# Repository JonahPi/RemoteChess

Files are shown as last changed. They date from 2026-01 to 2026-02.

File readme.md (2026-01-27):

## Summary

Remote Chess allows two board players or a board player and a App-user to compete online via a MQTT Broker. Lifting and placing of figures is detected by hall-sensors underneath the squares. The moves are published in an MQTT-topic called /remotechess. Boards subscribed to the topic get the moves from the topic and indicate them with NeoPixel LEDs which are integrated in the squares. Lifting a figure is indicated in red, placing a figure is indicated in green.

## Directory Structure

| Files / Directory | Description |
| --- | --- |
| [FSD Remote Chess.md](https://github.com/JonahPi/RemoteChess/blob/main/FSD%20Remote%20Chess.md) | Function Specification Document |
| CAD | CAD STEP File for Chess Board with electronic and cover |
| docs | Files used for Progressive Web App (PWA) published with Github Pages |
| Electronics | PCB schematic and Fritzing Files, Gerber Files |
| Micropython | ESP32 Micropython Program, Secrets File sample, Board-test-script, State-Diagram |
| pics | Project pictures |

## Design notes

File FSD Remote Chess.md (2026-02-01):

# FSD Remote Chess

## Summary

Remote Chess allows two board players to compete online via a MQTT Broker. Lifting and placing of figures is detected by hall-sensors underneath the squares. The moves are published in an MQTT-topic called /remotechess. Boards subscribed to the topic get the moves from the topic and indicate them with NeoPixel LEDs which are integrated in the squares. Lifting a figure is indicated in red, placing a figure is indicated in green.

## Board

The board has 8 times 8 fields setup in columns A to H and rows 1 to 8. Each field has a hall-sensor and a neopixel RGB LED.

The 64 Neopixel are organized in 8 rows so Fields A1 to H1 have the Neopixel numbers 1 to 8, the fields A2 to H2 have the Neopixel numbers 9 to 18 and so on till the fields A8 to H8 with Neopixel numbers 56 to 64.

The status of 64 hall sensors is detected by 8 PCBs, each of which has a MCP23017 GPIO Board Expander and 8 hall sensors to cover 1 row on the board. The 8 boards are all connected to an I2C bus. The board for the first row has the I2C address 0x27, the board for the second row has the address 0x26 and so on till the last row with board-address 0x20. The hall - sensors are connected to the  Inputs GPA0 to GPA7 of the Board expander, GPA0 corresponds to column A, GPA7 corresponds to column 7. 

##### Note: 

The ESP32 is located near the last row and the Neopixels are counted from there, this means that Fiel A8 (I2C address 0x20, GPA0) corresponds to the first Neopixel. Field H8 (I2C 0x27, GPA7) corresponds to the last Neopixel.

##### Concept

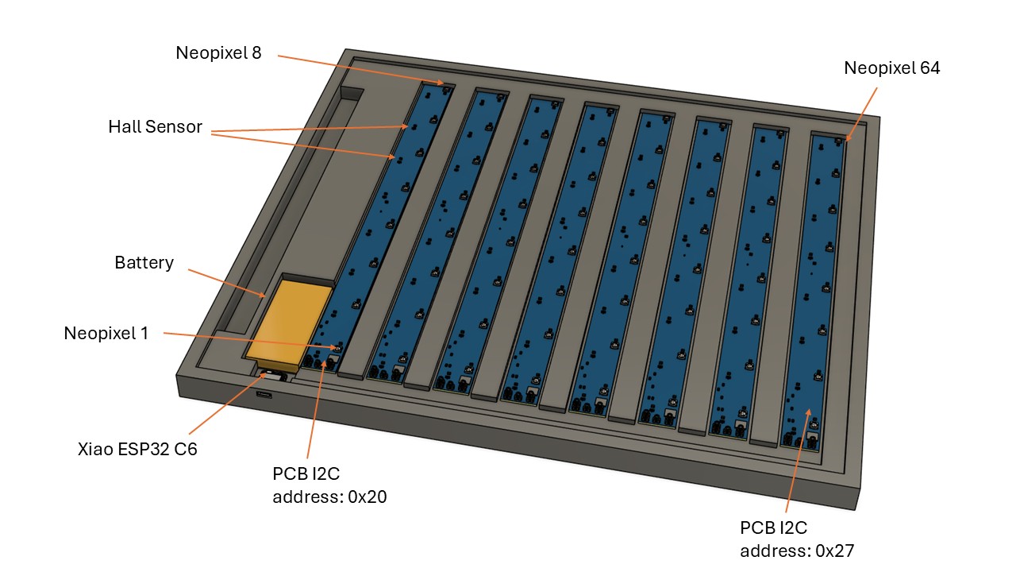
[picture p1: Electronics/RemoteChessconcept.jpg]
Remote Chess Concept


##### PCB Schematic (1x8 Row)

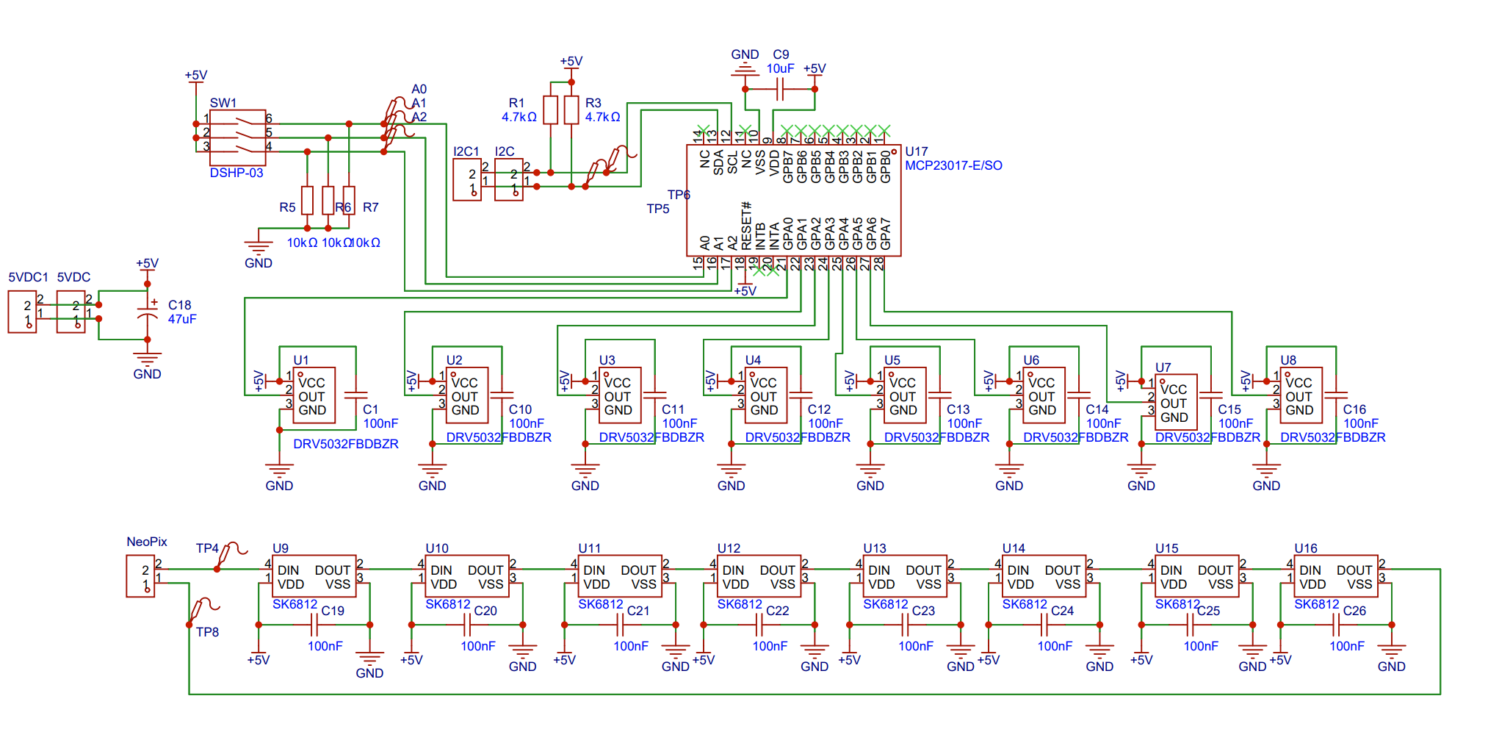
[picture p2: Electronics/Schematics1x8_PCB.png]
PCB Schematic for one row


| Quantity | Component | Comment |
| --- | --- | --- |
| 16 | 100nF | |
| 1 | 10uF | |
| 1 | 47uF | Stabilize Supply |
| 3 | 10kΩ | Pull up I2C address |
| 2 | 12kΩ | Pull up SDA, SCL |
| 1 | DSHP-03 | DIP-Switch for Address |
| 8 | DRV5032FBDBZR | Hall Sensor |
| 8 | SK6812 | Neopixel |
| 1 | MCP23017-E/SO | GPIO Port Expander |

#### Module test

The 8 PCBs shall be tested separately before the complete board assembly. To do this the I2C connections (SDA & SCL), the Neopixel data input (DIN) and the 5V input is directly connected to the XIAO ESP32-C6 (s.a. PIN assignement further below).

The test program has 3 steps:

1. Check if one of the permissible I2C addresses from 0x21 to 0x27 is set and print the address found in the serial terminal. 
2. Switch every single of the 8 Neopixel on and off in the 3 RGB colors, only one Neopixel at at a time shall be switched on. The frequency should be 500ms but configurable in a constant called frequency. So the test sequence looks like (Led 1 -> red -> green -> blue -> off, Led 2 -> red -> green -> blue -> off, ...and so on)
3. Switch in a loop which continuously detects the state of the hall-sensors, if a magnet is detected it should show the corresponding LED in green, if no magnet is detected the corresponding LED should be off. The brightness of the LEDs shall be reduced to 40%. Print the number of the hallsensors which detected a magnet in the serial window.

## ESP-Programming

### Program startup

During program startup, after initializing the hardware and before entering the main loop, the board shall perform a visual self-test by displaying the hall sensor status row by row:

1. For each row (1 to 8), read the hall sensor states and light up the corresponding LEDs for 1 second:
   - Fields with a magnet detected (figure present): RED
   - Fields without a magnet (no figure): GREEN
2. LED brightness during this startup routine shall be limited to 40%
3. After displaying a row for 1 second, turn off all LEDs before proceeding to the next row
4. After all 8 rows have been displayed, turn off all LEDs and proceed to the main loop

This startup sequence serves as a visual confirmation that all hall sensors and LEDs are functioning correctly. 

The startup sequence shall also be called when a re-start is triggered.

### Connection indication

After successfully connecting to the MQTT broker and subscribing to the topic, display a brief visual indication that the game is ready to start:

1. Light up D4 and E4 in green (place color)
2. Light up D5 and E5 in red (lift color)
3. Keep LEDs on for 1 second, then turn them off

This pattern indicates the center of the board and confirms the connection is established.

### Detecting and publishing movement

Figure movements is detected by a change in the hall-sensor state and indicated with LEDs, the actions cause MQTT messages to be send. The logic is defined in the state-diagram below.

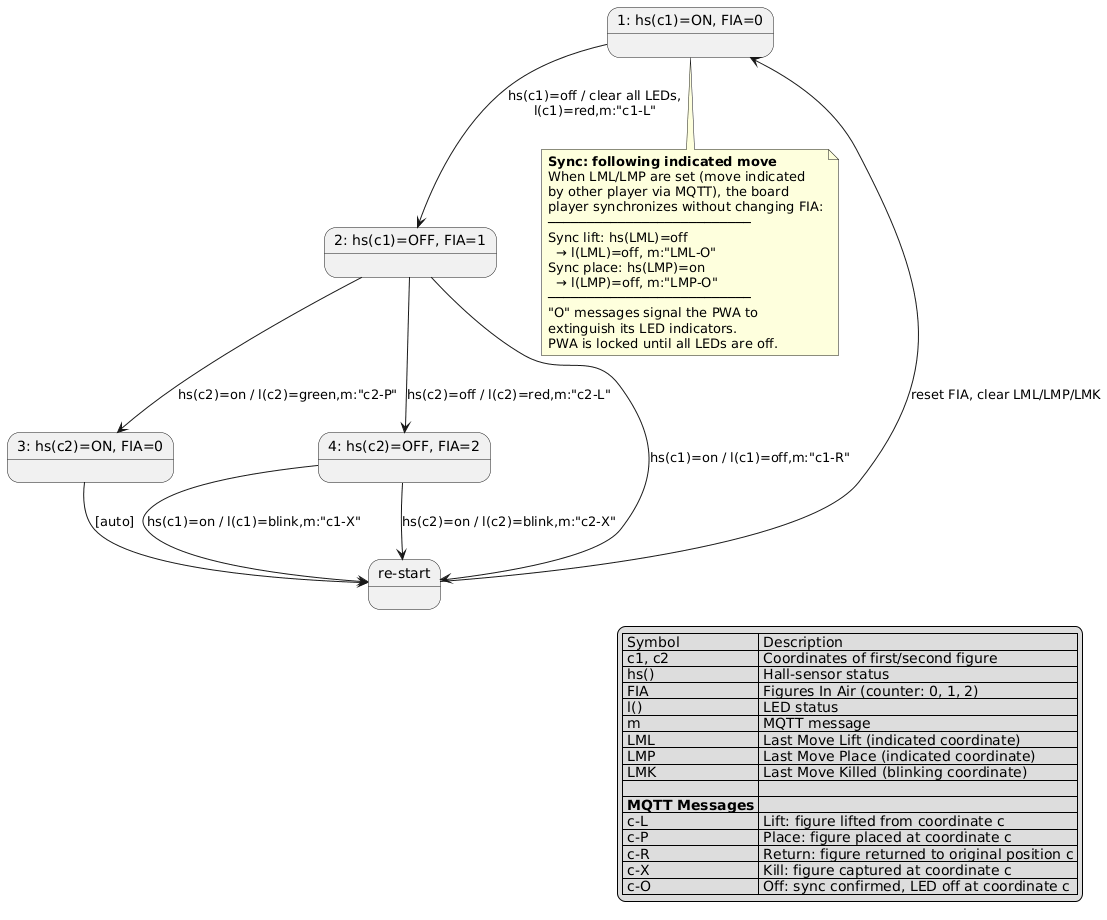
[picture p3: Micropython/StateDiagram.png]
StateDiagram


**Important:** The state variables LML, LMP and LMK shall only be updated by the MQTT callback when receiving messages, not by the hall sensor scanning function. This ensures that when the board receives its own published message, the LED control works correctly (the callback clears the OLD coordinates before setting the new ones). The hall sensor scanning function shall only update FiguresInAir and publish MQTT messages.

### Receiving and Indicating movement

New messages on topic /remotechess shall trigger the following actions:

| Message format | Action |
| --- | --- |
| *coordinate*-L | 1. switch the Neopixel corresponding to *coordinate* to red<br />2. set neopixels corresponding to coordinates stored in LML, LMP and LMK to *off* (skip if the variable is empty)<br />3. set values of LMP and LMK to ""<br />4. set value of LML to *coordinate*<br />5. stop the timer "fading" |
| *coordinate*-P | 1. switch the neopixel corresponding to *coordinate* to green<br />2. reset/start the timer "fading" and set it to 20s<br />3. set value of LMP to *coordinate*<br />4. if LMK is not empty, set it to "" and stop the blinking |
| *coordinate*-R | 1. switch the neopixel corresponding to *coordinate* to *off*<br />2. set value of LML to "" |
| *coordinate*-X | 1. switch the neopixel corresponding to *coordinate* to red blinking (200ms frequency)<br />2. set value of LMK to *coordinate*<br />3. reset/start the timer "fading" and set it to 20s |

When the timer fading expires, the Neopixels corresponding to the coordinates stored in LML, LMP and LMK shall be switched to *off* and all LEDs shall be switched to off.

### Moving figures to follow indicated movement

When the player receives a move which is indicated by the red and green LEDs, he is supposed to synchronize the figures on the chess field with the indicated move. This synchronization shall not trigger a MQTT message. As soon as he lifts the figure to be synchronized from the correct position, the red led shall be switched off, when he places the figure on the correct field the green LED shall be switched off. It is important that the "on"->"off" sequence (figure is lifted) and the "off"->"on" sequence (figure is placed) are correctly detected. In case a figure is killed in that move, the destination hall-sensor is "on" in the beginning. The figure to be killed is then lifted (on->off: which should not cause any action) and the new figure is placed (off->on: switching off green destination LED).

Till the move has been synchronized on the board, it shall not be possible to make a new move in the PWA. That the move has been synchronized on the board shall be indicated in the PWA by extinguishing the LEDs which indicated the movement in the app.

### Pin-assignment

The program shall be written in Micropython and suitable for the development board Xiao ESP32-C6. Use the following pins:

| Function | Pin Number |
| --- | --- |
| SCL | D5 |
| SDA | D4 |
| Neopixel | D7 |

### Secrets file

The access data (passwords, usernames, keys and IP-addresses) for the the Wifi and to the MQTT broker shall be stored in a dedicated secrets - file.

Time values, Blink-frequency and LED-colors shall be settable at the top of the pro

### MQTT Broker

Use the following MQTT Broker Configuration

```
MQTT_BROKER = "io.adafruit.com"  
MQTT_PORT = 1883                         # Default MQTT port
MQTT_USER = "your_adafruit_username"
MQTT_PASSWORD = "your_adafruit_key"      # Look for key-symbol in your adafruit account
MQTT_CLIENT_ID = "remote_chess_board_1"  # Unique ID for this board
MQTT_TOPIC = "YourUserName/feeds/chess"  # MQTT topic for chess moves, adapt your username
```

### Demo mode

Add a flag DemoMode which can be set at the beginning of the program. In demo-mode the hall-sensors are not connected and no expander boards. In this mode the program shall just check for the updates on the MQTT topic and control the neopixel stripe with 64 LEDs. The received updates and the color and number of the activated neopixel shall be shown in the serial monitor.

## **Progressive Web App (PWA**)

### Summary

The Web App allows the simulation of the real chess board. So one player can use the app and the other player uses the real board. Alternatively both players can use the app or both players can use a real board

### Architecture

The Web App shall be hosted as page in the Git-repository for this project ([Remote Chess](https://jonahpi.github.io/RemoteChess/)). The Web App shall simulate the Chess-board and shall be optimized for an iPhone 16 from the layout. By touching a figure ones it is activated for moving. Touching a field afterwards will place the figure there. In case the destination field was not empty, the destination figure is replaced with the figure which has been selected. When moving the figures no chess rules need to be considered. Touching the figure shall have the same effect as lifting a figure on the real chess box including the MQTT message. The LEDs shall be simulated by small dots on the simulated chess field. 

When starting the program it shall automatically try to connect, when it gets disconnected it shall try to reconnect.

A button called "Zurück" allows to undo the latest action on App. It will move the figures which has been moved by the user back to the last position, the LEDs are switched off and in case another figure has been killed, the figure should be replaced to its original position. "Zurück" only needs to work for one move. the button shall be greyed out when it has been used and re-activated after the next move. When "Zurück" has been clicked, send the message "undo" to the MQTT topic. When receiving the MQTT message "undo", undo the last figure placement.

A button called "Neu starten" will reset the board to the start position. White is on the bottom, black on the top. This will also trigger the startup-sequence and a MQTT message "restart". The MQTT message indicates the other player that the game has restarted. When the ESP32 receives the "restart" message, the startup-sequence shall be triggered.

A button called "Wechsel" shall flip the entire board updside down, so that the player sees the black figures on the bottom and the white figures on the top. Pressing the button again, switches back to the original setup with white figures on the bottom and black on the top.

When the App receives a MQTT message of type *coordinate*-L which has not been triggered by touching a figure in the app itself, this means that the other player has lifted a figure. The App shall then wait for the message that a figure has been placed (*coordinate*-P) and move the corresponding icon from the lift-coordinates to the place-coordinates.

When the lift location and the place location of a pawn is the same and the pawn is in row 1 or in row 8, change the pawn to a Queen, if it is lifted and placed again to the same location, change it back to a pawn. All other figures and pawns in all other rows, shall remain the same when they are lifted and placed on the same location.

### Icon Design

 All chess figures are depicted by simple icons. the Icons for one player shall be black, the ones for the other player white

1. **Black pieces** - Displayed in pure black color (#000)
2. **White pieces** - Displayed in white with a black outline/shadow so they're visible on light squares
3. **Consistent rendering** - All pieces now use the same Unicode symbols but with CSS styling to ensure they look uniform
4. **Black party**: Black icons (♚ ♛ ♜ ♝ ♞ ♟)
5. **White party**: White icons with black outline (♔ ♕ ♖ ♗ ♘ ♙)
6. Enforce the usage of the fonts `Noto Sans Symbols` or `Chess Merida`for rendering the symbols.

### Screen Layout

The chess board shall be square an take the full width of the screen. On the top shall be a status indication which states if the program is still connected to the MQTT Broker. 

Below the chess board, the 3 buttons are placed in the order: Wechsel, Zurück, Neu starten

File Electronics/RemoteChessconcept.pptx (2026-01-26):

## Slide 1

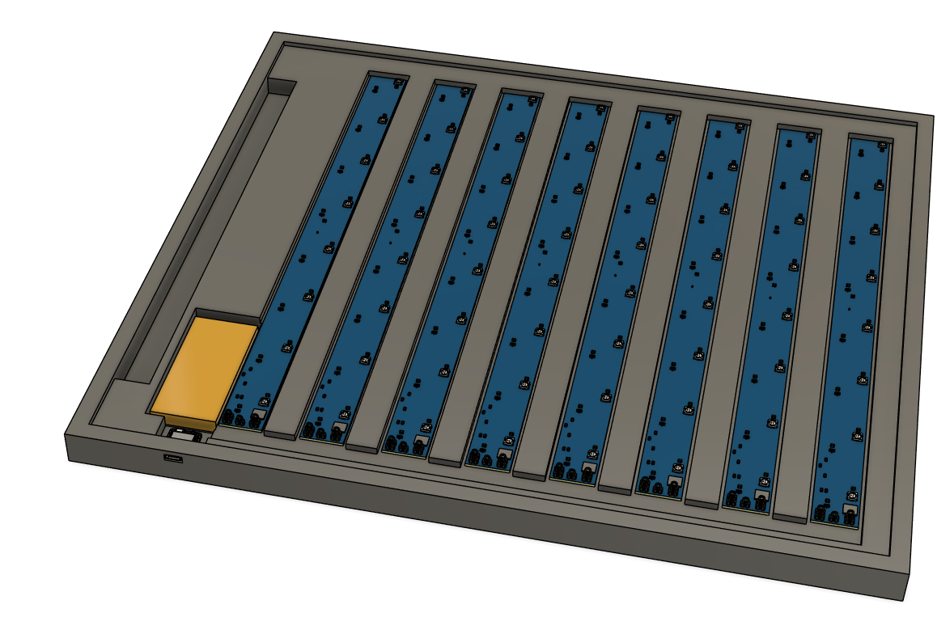
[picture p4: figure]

Neopixel 8

Neopixel 64

Hall Sensor

Battery

Neopixel 1

Xiao ESP32 C6

PCB I2C
address: 0x20

PCB I2C
address: 0x27

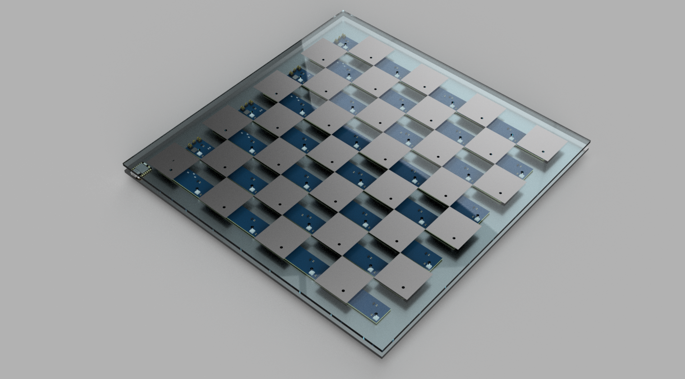
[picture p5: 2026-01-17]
pics/RemoteChess v5.png

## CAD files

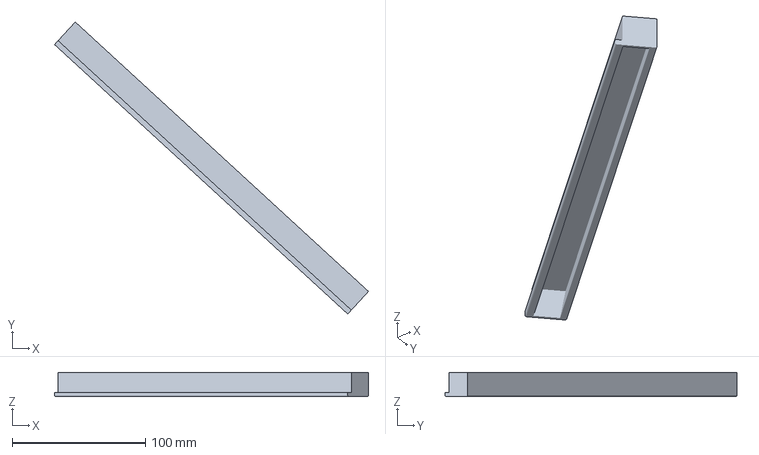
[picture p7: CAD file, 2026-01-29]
CAD/ipadInlay.3mf
235.3 x 218.8 x 18.0 mm

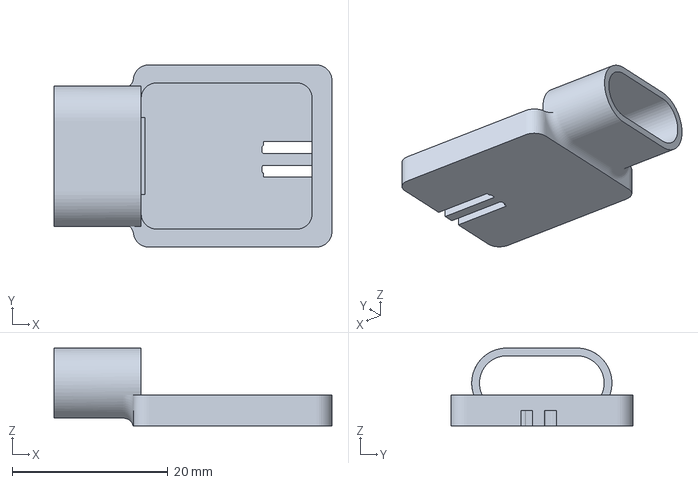
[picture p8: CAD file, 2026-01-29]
CAD/ESP32_Inlay.3mf
35.7 x 23.4 x 10.0 mm

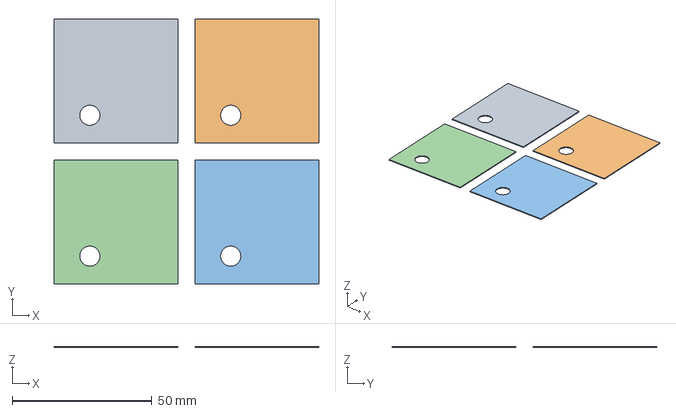
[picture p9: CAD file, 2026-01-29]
CAD/4xChessFields.3mf
94.8 x 94.8 x 0.4 mm

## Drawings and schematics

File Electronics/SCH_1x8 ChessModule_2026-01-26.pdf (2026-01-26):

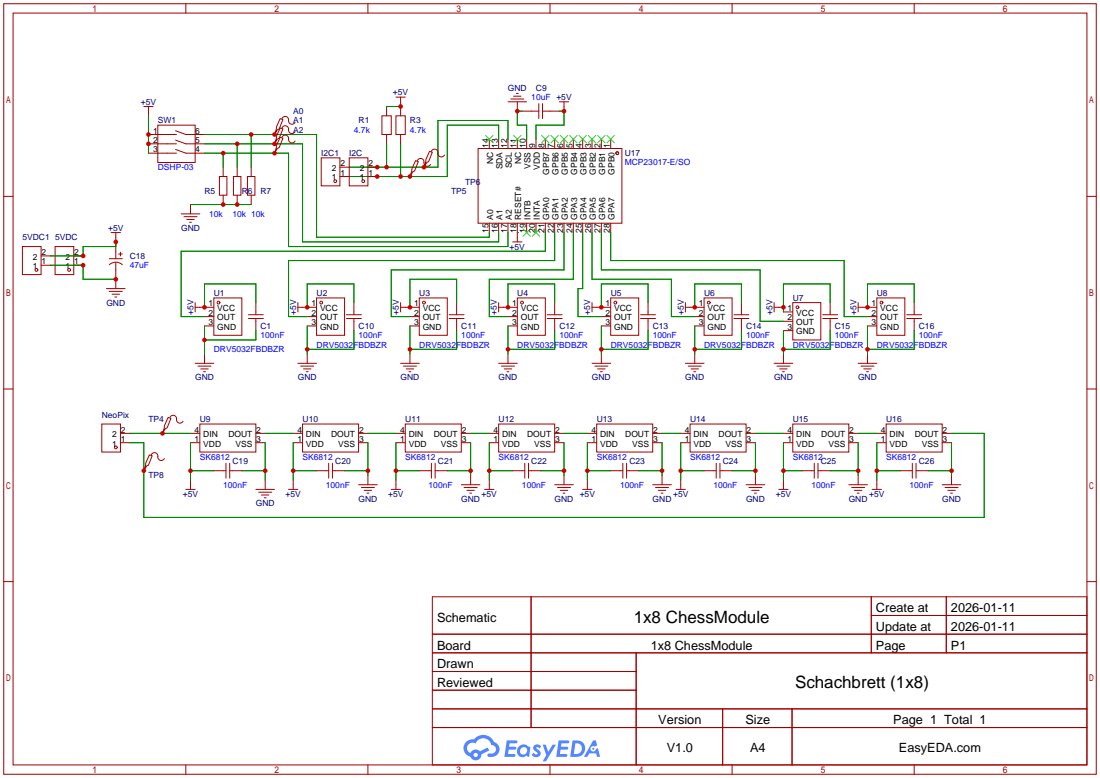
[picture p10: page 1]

9 VSS 10 NC 11 SCL 12 SDA 13 NC 14 A0 15 A1 16 A2 17 RESET# 18 INTB 19 INTA 20

Schematic | 1x8 ChessModule | Create at | 2026-01-11

Update at | 2026-01-11

Board | 1x8 ChessModule | Page | P1
Drawn | | Schachbrett (1x8)
Reviewed

Version | Size | Page 1 Total 1
V1.0 | A4 | EasyEDA.com

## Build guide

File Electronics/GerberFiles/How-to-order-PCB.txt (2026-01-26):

How to Order PCB

Please refer to:
https://prodocs.easyeda.com/en/pcb/order-order-pcb/index.html

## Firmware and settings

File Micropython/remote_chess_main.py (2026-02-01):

"""
FSD Remote Chess - Main Program
For Xiao ESP32-C6 with MicroPython
"""

import network
import time
import json
import socket
from machine import Pin, I2C, Timer
from neopixel import NeoPixel
from umqtt.simple import MQTTClient
from secrets import *

# ============= CONFIGURATION =============
# Demo Mode - Set to True to run without hall sensors
DEMO_MODE = False  # Set to True for testing without hardware

# LED Colors (R, G, B)
COLOR_LIFT = (100, 0, 0)      # Red for lifted pieces
COLOR_PLACE = (0, 100, 0)     # Green for placed pieces
COLOR_KILLED = (100, 0, 0)    # Red for killed pieces
COLOR_OFF = (0, 0, 0)         # Off

# Timing
FADING_TIMEOUT_MS = 15000     # 20 seconds
BLINK_FREQUENCY_MS = 400      # 200ms for blinking
STARTUP_ROW_DURATION_MS = 800  # 800ms per row during startup

# Startup brightness (40% = 0.4)
STARTUP_BRIGHTNESS = 0.4

# Pin Configuration (Xiao ESP32-C6)
PIN_SDA = 22  # D4 = GPIO22
PIN_SCL = 23  # D5 = GPIO23
PIN_NEOPIXEL = 18  # D10 = GPIO18

# Board Configuration
NUM_NEOPIXELS = 64
MCP23017_ADDRESSES = [0x20, 0x21, 0x22, 0x23, 0x24, 0x25, 0x26, 0x27]

# ============= GLOBAL VARIABLES =============
LML = ""  # Last Move Lift
LMP = ""  # Last Move Place
LMK = ""  # Last Move Killed (coordinate with blinking LED)

# State machine variables per FSD
FiguresInAir = 0  # Counter: 0, 1, or 2
first_lift_coord = ""  # Coordinate of first lifted piece (c1)
second_lift_coord = ""  # Coordinate of second lifted piece (c2)

# Hardware objects
i2c = None
np = None
mqtt_client = None
fading_timer = None
blink_timer = None
blink_state = False

# Track previous hall sensor states (only used in non-demo mode)
previous_hall_states = [[False] * 8 for _ in range(8)]

# MQTT keep-alive tracking
last_mqtt_activity = 0  # Reset on any MQTT publish

# ============= MCP23017 Functions =============
def mcp23017_init(i2c, address):
    """Initialize MCP23017 - set all pins as inputs with pull-ups"""
    # IODIRA register (0x00) - set all as inputs (0xFF)
    i2c.writeto_mem(address, 0x00, b'\xFF')
    # GPPUA register (0x0C) - enable pull-ups
    i2c.writeto_mem(address, 0x0C, b'\xFF')

def mcp23017_read_gpio(i2c, address):
    """Read GPIOA register (0x12) from MCP23017"""
    data = i2c.readfrom_mem(address, 0x12, 1)
    return data[0]

# ============= Coordinate Conversion =============
def sensor_to_coordinate(row_idx, col):
    """Convert row_idx (0-7) and column (0-7) to chess coordinate.

    Note: I2C addresses are mapped as follows:
    - row_idx 0 (I2C 0x20) = Chess Row 8
    - row_idx 7 (I2C 0x27) = Chess Row 1
    """
    column_letter = chr(ord('A') + col)
    row_number = 8 - row_idx  # row_idx 0 -> row 8, row_idx 7 -> row 1
    return f"{column_letter}{row_number}"

def coordinate_to_neopixel(coord):
    """Convert chess coordinate (e.g., 'A1') to neopixel index (0-63).

    Note: Neopixels are counted from A8 (index 0) to H1 (index 63).
    - A8 = 0, H8 = 7
    - A1 = 56, H1 = 63
    """
    col = ord(coord[0]) - ord('A')
    chess_row = int(coord[1])
    row_idx = 8 - chess_row  # row 8 -> idx 0, row 1 -> idx 7
    return row_idx * 8 + col

# ============= NeoPixel Functions =============
def set_neopixel(coord, color):
    """Set neopixel at coordinate to specified color"""
    if coord:
        idx = coordinate_to_neopixel(coord)
        np[idx] = color
        np.write()
        if DEMO_MODE:
            print(f"[DEMO] NeoPixel #{idx} ({coord}) -> RGB{color}")

def clear_neopixels(coords):
    """Clear neopixels at given coordinates"""
    for coord in coords:
        if coord:
            set_neopixel(coord, COLOR_OFF)

def blink_callback(timer):
    """Timer callback for blinking effect"""
    global blink_state, LMK
    if LMK:
        blink_state = not blink_state
        color = COLOR_KILLED if blink_state else COLOR_OFF
        set_neopixel(LMK, color)

def fading_callback(timer):
    """Timer callback for fading timeout"""
    global LML, LMP, LMK
    if DEMO_MODE:
        print(f"[DEMO] Fading timeout - clearing all LEDs")
    # Clear specific coordinates
    clear_neopixels([LML, LMP, LMK])
    # Clear all LEDs
    for i in range(NUM_NEOPIXELS):
        np[i] = COLOR_OFF
    np.write()
    # Reset state variables
    LML = ""
    LMP = ""
    LMK = ""
    if blink_timer:
        blink_timer.deinit()

# ============= MQTT Functions =============
def mqtt_callback(topic, msg):
    """Handle incoming MQTT messages"""
    global LML, LMP, LMK, fading_timer, blink_timer, previous_hall_states

    message = msg.decode('utf-8')
    print(f"Received: {message}")

    # Handle restart message
    if message == "restart":
        global FiguresInAir, first_lift_coord, second_lift_coord
        print("Restart triggered - running startup sequence")
        # Clear all state
        LML = ""
        LMP = ""
        LMK = ""
        FiguresInAir = 0
        first_lift_coord = ""
        second_lift_coord = ""
        if fading_timer:
            fading_timer.deinit()
        if blink_timer:
            blink_timer.deinit()
        # Clear all LEDs
        for i in range(NUM_NEOPIXELS):
            np[i] = COLOR_OFF
        np.write()
        # Run startup sequence and re-read hall sensor states
        if not DEMO_MODE:
            startup_led_test()
            # Re-initialize hall sensor states after restart
            for row_idx, address in enumerate(MCP23017_ADDRESSES):
                try:
                    gpio_state = mcp23017_read_gpio(i2c, address)
                    for col_idx in range(8):
                        previous_hall_states[row_idx][col_idx] = (gpio_state & (1 << col_idx)) == 0
                except Exception as e:
                    print(f"Error reading state after restart: {e}")
        return

    if len(message) < 4:
        return

    coord = message[:-2]  # Extract coordinate (e.g., 'A4' from 'A4-L')
    action = message[-1]  # Extract action ('L', 'P', 'R', or 'X')
    
    if action == 'L':
        # Lift action
        if DEMO_MODE:
            print(f"[DEMO] Lift detected at {coord}")
        set_neopixel(coord, COLOR_LIFT)
        clear_neopixels([LML, LMP, LMK])
        LMP = ""
        LMK = ""
        LML = coord
        if fading_timer:
            fading_timer.deinit()
    
    elif action == 'P':
        # Place action
        if DEMO_MODE:
            print(f"[DEMO] Place detected at {coord}")
        set_neopixel(coord, COLOR_PLACE)
        LMP = coord
        # If LMK is not empty, clear it and stop blinking
        if LMK:
            if DEMO_MODE:
                print(f"[DEMO] Clearing killed piece at {LMK} and stopping blink")
            LMK = ""
            if blink_timer:
                blink_timer.deinit()
        if fading_timer:
            fading_timer.deinit()
        fading_timer = Timer(0)
        fading_timer.init(mode=Timer.ONE_SHOT, period=FADING_TIMEOUT_MS, callback=fading_callback)

    elif action == 'R':
        # Return action - figure returned to original position
        if DEMO_MODE:
            print(f"[DEMO] Figure returned to {coord}")
        set_neopixel(coord, COLOR_OFF)
        LML = ""

    elif action == 'X':
        # Killed action
        if DEMO_MODE:
            print(f"[DEMO] Piece killed at {coord}")
        LMK = coord
        if blink_timer:
            blink_timer.deinit()
        blink_timer = Timer(1)
        blink_timer.init(mode=Timer.PERIODIC, period=BLINK_FREQUENCY_MS, callback=blink_callback)
        # Start fading timer so blinking LED turns off after timeout
        if fading_timer:
            fading_timer.deinit()
        fading_timer = Timer(0)
        fading_timer.init(mode=Timer.ONE_SHOT, period=FADING_TIMEOUT_MS, callback=fading_callback)

    elif action == 'O':
        # Sync indication echo from board - ignore on receive
        pass

def publish_move(message):
    """Publish move to MQTT topic"""
    global last_mqtt_activity
    try:
        mqtt_client.publish(MQTT_TOPIC, message)
        last_mqtt_activity = time.time()  # Reset ping timer
        print(f"Published: {message}")
    except Exception as e:
        print(f"MQTT publish error: {e}")

# ============= Hall Sensor Scanning =============
def scan_hall_sensors():
    """Scan all hall sensors and detect changes.

    State machine per FSD:
    - State 1: FIA=0, waiting for first lift
    - State 2: FIA=1, one piece lifted (c1)
    - State 3: FIA=0, piece placed (move complete)
    - State 4: FIA=2, two pieces lifted (capture scenario)

    Transitions:
    - State 1 → 2: lift → FIA=1, send "c1-L"
    - State 2 → 3: place at new coord → FIA=0, send "c2-P"
    - State 2 → 4: lift second piece → FIA=2, send "c2-L"
    - State 4 → restart: place → FIA=0, send "cX-X" (capture)
    - State 2 → restart: place back at c1 → FIA=0, send "c1-P"

    When LEDs indicate a move from the other player (LML/LMP set),
    synchronizing figures to follow that move does NOT trigger MQTT messages.
    """
    global FiguresInAir, first_lift_coord, second_lift_coord, previous_hall_states, LML, LMP, LMK, fading_timer, blink_timer

    for row_idx, address in enumerate(MCP23017_ADDRESSES):
        try:
            gpio_state = mcp23017_read_gpio(i2c, address)

            for col_idx in range(8):
                # Check if bit is LOW (0 = magnet detected = figure present, with pull-ups)
                current_state = (gpio_state & (1 << col_idx)) == 0
                previous_state = previous_hall_states[row_idx][col_idx]

                # Detect state change
                if current_state != previous_state:
                    coord = sensor_to_coordinate(row_idx, col_idx)

                    # Figure removed (was present, now absent)
                    if previous_state and not current_state:
                        # Check if this is synchronizing to an indicated move (lift from LML)
                        if coord == LML:
                            # Player is following indicated move - indicate sync to PWA
                            print(f"Sync lift at {coord} (following indicated move)")
                            set_neopixel(coord, COLOR_OFF)
                            LML = ""
                            publish_move(f"{coord}-O")
                        elif FiguresInAir == 0:
                            # State 1 → State 2: First lift
                            # FSD: restart → State 1 clears all LEDs
                            clear_neopixels([LML, LMP, LMK])
                            LML = ""
                            LMP = ""
                            LMK = ""
                            if fading_timer:
                                fading_timer.deinit()
                            if blink_timer:
                                blink_timer.deinit()
                            FiguresInAir = 1
                            first_lift_coord = coord
                            publish_move(f"{coord}-L")
                        elif coord == LMP:
                            # Player is removing killed piece from destination - no action
                            # Green LED stays on until new piece is placed
                            print(f"Sync kill removal at {coord} (removing captured piece)")
                        elif FiguresInAir == 1:
                            # State 2 → State 4: Second lift (capture scenario)
                            FiguresInAir = 2
                            second_lift_coord = coord
                            publish_move(f"{coord}-L")  # FSD: send L, not X

                    # Figure placed (was absent, now present)
                    elif not previous_state and current_state:
                        # Check if this is synchronizing to an indicated move (place at LMP)
                        if coord == LMP:
                            # Player is following indicated move - indicate sync to PWA
                            print(f"Sync place at {coord} (following indicated move)")
                            set_neopixel(coord, COLOR_OFF)
                            LMP = ""
                            publish_move(f"{coord}-O")
                        elif FiguresInAir == 1:
                            # State 2: One piece in air
                            if coord == first_lift_coord:
                                # State 2 → restart: Return to original position
                                FiguresInAir = 0
                                first_lift_coord = ""
                                publish_move(f"{coord}-R")  # FSD: send R for return
                            else:
                                # State 2 → State 3 → restart: Normal move
                                FiguresInAir = 0
                                first_lift_coord = ""
                                publish_move(f"{coord}-P")
                        elif FiguresInAir == 2:
                            # State 4 → restart: Capture placement
                            # When placing while 2 pieces are in air, this is a capture
                            FiguresInAir = 0
                            first_lift_coord = ""
                            second_lift_coord = ""
                            publish_move(f"{coord}-X")  # FSD: send X for capture

                    previous_hall_states[row_idx][col_idx] = current_state

        except Exception as e:
            print(f"Error reading MCP23017 at 0x{address:02X}: {e}")

# ============= Startup Routine =============
def startup_led_test():
    """Display hall sensor status row by row during startup"""
    print("Running startup LED test...")

    # Calculate dimmed colors (40% brightness)
    color_red = tuple(int(c * STARTUP_BRIGHTNESS) for c in COLOR_LIFT)
    color_green = tuple(int(c * STARTUP_BRIGHTNESS) for c in COLOR_PLACE)

    for row_idx, address in enumerate(MCP23017_ADDRESSES):
        try:
            # Read hall sensor state for this row
            gpio_state = mcp23017_read_gpio(i2c, address)

            # Light up LEDs for this row
            for col_idx in range(8):
                # Check if magnet detected (LOW = magnet present)
                magnet_present = (gpio_state & (1 << col_idx)) == 0
                led_idx = row_idx * 8 + col_idx

                if magnet_present:
                    np[led_idx] = color_red    # Red for magnet/figure present
                else:
                    np[led_idx] = color_green  # Green for no magnet/empty

            np.write()
            print(f"Row {row_idx + 1} (0x{address:02X}): displayed")

            # Wait 1 second
            time.sleep(STARTUP_ROW_DURATION_MS / 1000)

            # Turn off this row before next
            for col_idx in range(8):
                led_idx = row_idx * 8 + col_idx
                np[led_idx] = COLOR_OFF
            np.write()

        except Exception as e:
            print(f"Error in startup test row {row_idx + 1}: {e}")

    print("Startup LED test complete")

# ============= WiFi Manager =============
WIFI_CONFIG_FILE = "wifi_config.json"
AP_SSID = "RemoteChess-Setup"

def url_decode(s):
    """Simple URL decoder for form data"""
    s = s.replace('+', ' ')
    parts = s.split('%')
    result = parts[0]
    for part in parts[1:]:
        if len(part) >= 2:
            try:
                result += chr(int(part[:2], 16)) + part[2:]
            except ValueError:
                result += '%' + part
        else:
            result += '%' + part
    return result

def load_wifi_config():
    """Load WiFi credentials from permanent storage"""
    try:
        with open(WIFI_CONFIG_FILE, 'r') as f:
            config = json.load(f)
            return config.get('ssid', ''), config.get('password', '')
    except:
        return '', ''

def save_wifi_config(ssid, password):
    """Save WiFi credentials to permanent storage"""
    config = {'ssid': ssid, 'password': password}
    with open(WIFI_CONFIG_FILE, 'w') as f:
        json.dump(config, f)
    print(f"WiFi config saved for network: {ssid}")

def scan_wifi_networks():
    """Scan for available WiFi networks"""
    wlan = network.WLAN(network.STA_IF)
    wlan.active(True)
    networks = wlan.scan()
    wlan.active(False)
    seen = set()
    unique = []
    for net in networks:
        ssid = net[0].decode('utf-8') if isinstance(net[0], bytes) else net[0]
        if ssid and ssid not in seen:
            seen.add(ssid)
            unique.append((ssid, net[3]))
    unique.sort(key=lambda x: x[1], reverse=True)
    return unique

def generate_wifi_html(networks):
    """Generate HTML page for WiFi network selection"""
    options = ''
    for ssid, rssi in networks:
        options += '<option value="' + ssid + '">' + ssid + ' (' + str(rssi) + ' dBm)</option>'
    return ('<!DOCTYPE html><html><head>'
        '<meta name="viewport" content="width=device-width, initial-scale=1">'
        '<title>Remote Chess WiFi Setup</title>'
        '<style>'
        'body{font-family:Arial;margin:20px;background:#1a1a2e;color:#eee;}'
        'h1{color:#e94560;}h2{color:#aaa;}'
        'select,input,button{width:100%;padding:12px;margin:8px 0;'
        'box-sizing:border-box;font-size:16px;border-radius:4px;border:1px solid #555;}'
        'select,input{background:#16213e;color:#eee;}'
        'button{background:#e94560;color:white;border:none;cursor:pointer;}'
        '.c{max-width:400px;margin:0 auto;}'
        '</style></head><body><div class="c">'
        '<h1>Remote Chess</h1><h2>WiFi Setup</h2>'
        '<form action="/connect" method="POST">'
        '<label>Select Network:</label>'
        '<select name="ssid">' + options + '</select>'
        '<label>Password:</label>'
        '<input type="password" name="password" placeholder="Enter WiFi password">'
        '<button type="submit">Connect</button>'
        '</form></div></body></html>')

def start_wifi_manager():
    """Start WiFi Manager AP with web portal for network selection"""
    print("Scanning WiFi networks...")
    networks = scan_wifi_networks()
    print(f"Found {len(networks)} networks")

    ap = network.WLAN(network.AP_IF)
    ap.active(True)
    ap.config(essid=AP_SSID)

    print(f"WiFi Manager AP started: {AP_SSID}")
    print("Connect to this network and open http://192.168.4.1")

    addr = socket.getaddrinfo('0.0.0.0', 80)[0][-1]
    s = socket.socket()
    s.setsockopt(socket.SOL_SOCKET, socket.SO_REUSEADDR, 1)
    s.bind(addr)
    s.listen(1)

    html_page = generate_wifi_html(networks)

    try:
        while True:
            cl, cl_addr = s.accept()
            try:
                request = cl.recv(1024).decode('utf-8')

                if 'POST /connect' in request:
                    body = request.split('\r\n\r\n')[-1]
                    params = {}
                    for param in body.split('&'):
                        if '=' in param:
                            key, value = param.split('=', 1)
                            params[key] = url_decode(value)

                    ssid = params.get('ssid', '')
                    password = params.get('password', '')

                    if ssid:
                        response = ('<!DOCTYPE html><html><head>'
                            '<meta name="viewport" content="width=device-width, initial-scale=1">'
                            '<style>body{font-family:Arial;margin:20px;background:#1a1a2e;'
                            'color:#eee;text-align:center;}h1{color:#e94560;}</style>'
                            '</head><body>'
                            '<h1>Connecting to ' + ssid + '...</h1>'
                            '<p>The board will connect to the selected network.</p>'
                            '<p>You can close this page.</p>'
                            '</body></html>')
                        cl.send('HTTP/1.0 200 OK\r\nContent-Type: text/html\r\n\r\n')
                        cl.send(response)
                        cl.close()

                        save_wifi_config(ssid, password)
                        ap.active(False)
                        s.close()
                        return ssid, password
                else:
                    cl.send('HTTP/1.0 200 OK\r\nContent-Type: text/html\r\n\r\n')
                    cl.send(html_page)
            except Exception as e:
                print(f"WiFi Manager error: {e}")
            finally:
                try:
                    cl.close()
                except:
                    pass
    except Exception as e:
        print(f"WiFi Manager server error: {e}")
        s.close()
        ap.active(False)
        raise
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

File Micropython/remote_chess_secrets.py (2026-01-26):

"""
FSD Remote Chess - Secrets Configuration File
Copy this file as 'secrets.py' and fill in your credentials
"""

# WiFi Configuration
WIFI_SSID = "your_wifi_ssid"
WIFI_PASSWORD = "your_wifi_password"

# MQTT Broker Configuration
MQTT_BROKER = "broker.example.com"  # IP address or hostname
MQTT_PORT = 1883                     # Default MQTT port
MQTT_USER = "your_mqtt_username"     # Leave empty string "" if no auth
MQTT_PASSWORD = "your_mqtt_password" # Leave empty string "" if no auth
MQTT_CLIENT_ID = "remote_chess_board_1"  # Unique ID for this board
MQTT_TOPIC = "ToniTwn/feeds/chess"   # MQTT topic for chess moves

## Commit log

2026-01-17 Initial upload
    [chess.fzz]
2026-01-17 Undo button
2026-01-19 wechsel button
2026-01-21 Corrected Pin-numbers
2026-01-25 Fix hall sensor state machine to match FSD specification
    Changed FigureInAir from boolean to counter (0,1,2) to properly track
    capture scenarios. Second piece lift now sends "L" message instead of "X",
    and placement during capture (FIA=2) sends "X" message. Added tracking
    variables for first/second lift coordinates.
    [remote_chess_main.py]
2026-01-25 Fix FSD consistency issues and typos
    - Consolidate symbol definitions into PlantUML legend (remove redundancy)
    - Fix LMX → LMK throughout for consistent variable naming
    - Fix typos: correesponding, correspondig
    - Use hs() consistently in state transitions
    - Add [auto] label to unlabeled state3 → restart transition
    - Fix FigureInAir → FiguresInAir to match implementation
2026-01-25 Fix PWA capture handling to match FSD state machine
    - Track both lifted pieces (c1 and c2) for capture scenarios
    - Handle both capture orders: attacker-first or victim-first
    - On second L message, keep first LED red (don't clear)
    - On X message, determine attacker origin based on X coordinate:
    - X at c1 means attacker came from c2
    - X at c2 means attacker came from c1
    - Add R message handling for return-to-origin
    - Properly move pieces and update board on capture
2026-01-25 Fix fading timer for killed figures
    - MicroPython: Start fading timer on X message so blinking LED
    turns off after 20s timeout
    - FSD: Document that X message also starts the fading timer
    [remote_chess_main.py]
2026-01-25 Change connection indication from D3/E3 to D5/E5
    Red LEDs now at D5/E5 (above green D4/E4) for symmetric center pattern.
2026-01-29 3D files
    [4xChessFields.3mf, ESP32_Inlay.3mf]
2026-01-29 ipad Inlay
    [ipadInlay.3mf]
